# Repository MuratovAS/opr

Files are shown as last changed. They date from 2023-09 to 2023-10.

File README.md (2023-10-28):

# OPR
Open pocket router

## Screenshots

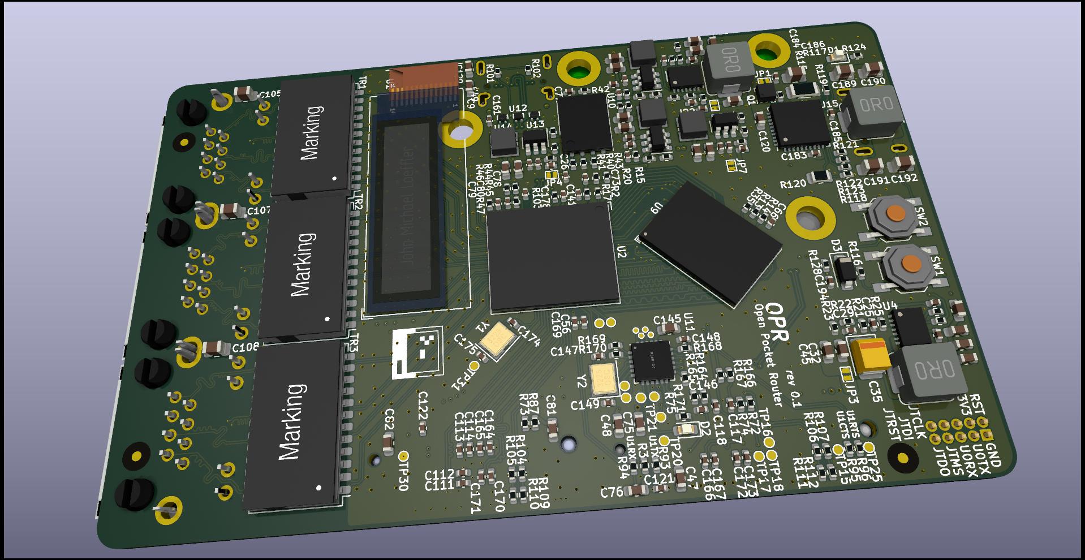
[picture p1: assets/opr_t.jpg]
Top view

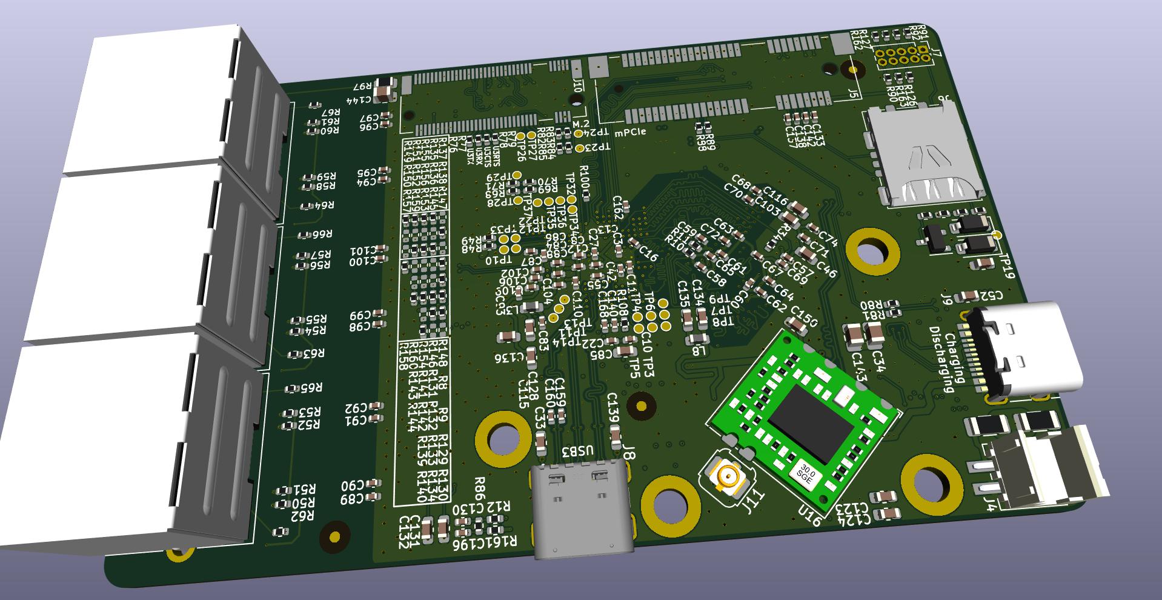
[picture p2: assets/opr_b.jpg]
Bottom view

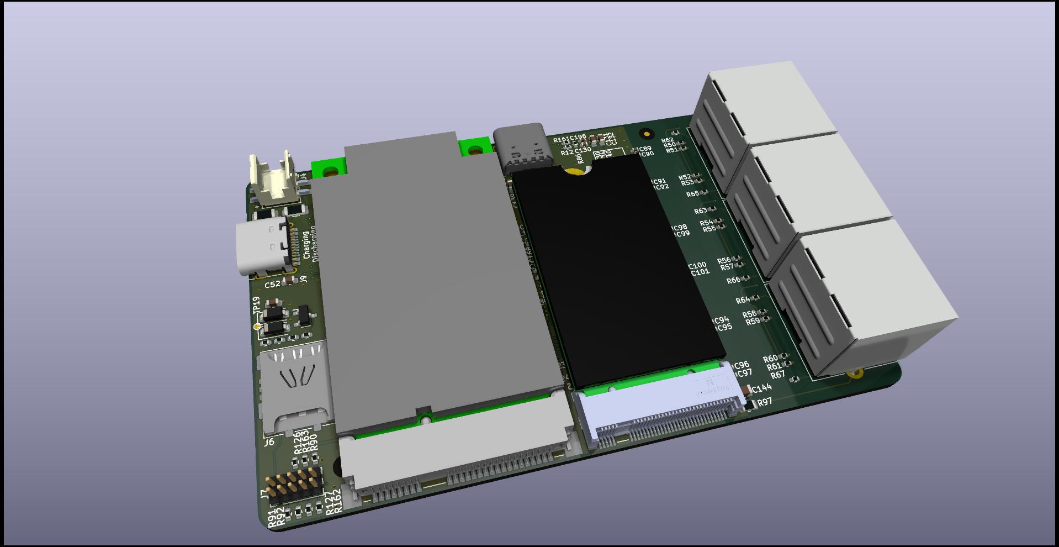
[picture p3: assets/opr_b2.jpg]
Bottom view 2


## In developing!!!

If you have questions, write suggestions in `Issues`

## Description
TODO:

## Specification

- CPU: MT7621A
- RAM: 2Gbit DDR3 
- USB: 3.0
- ETH: 3xGbE (RJ45)
- Display: SSD1306-0.91
- Flash: W25Q256FVEIG
- PowerBank: IP5328P
- Connectors: M.2 (2xPCIe+UART); mPCIe (1xPCIe+I2C+USB2+UART)
- PCB: 6 layers; JLC06161H-3313; Epoxy Filled & Capped; 0.15mm/0.3mm Via 

## Supported modules

- WIFI: MT7612E/MT7603E (x2 mPCIe)

## Changelog:

### v 0.1
- init

## Credit
```
https://github.com/kellertk/pwnagotchi-plugin-pisugar2
https://github.com/YC-Lammy/IP5328P-powerbank_design
https://github.com/zhaoxinyu0113/MT7621A_Router_HW_DIY'
https://github.com/cyijun/MT7621A-Router-Design
https://www.cnx-software.com/2015/05/14/firewrt-is-an-openwrt-802-11ac-board-powered-by-mediatek-mt7621a-processor/
https://bbs.t-firefly.com/forum.php?mod=viewthread&tid=543
http://en.techinfodepot.shoutwiki.com/wiki/Firefly_FireWRT
https://wikidevi.wi-cat.ru/MediaTek
https://whycan.com/t_2230.html
http://bbs.ntpcb.com/read-htm-tid-44619.html
https://www.elecfans.com/soft/21/2020/202003111179546.html
```

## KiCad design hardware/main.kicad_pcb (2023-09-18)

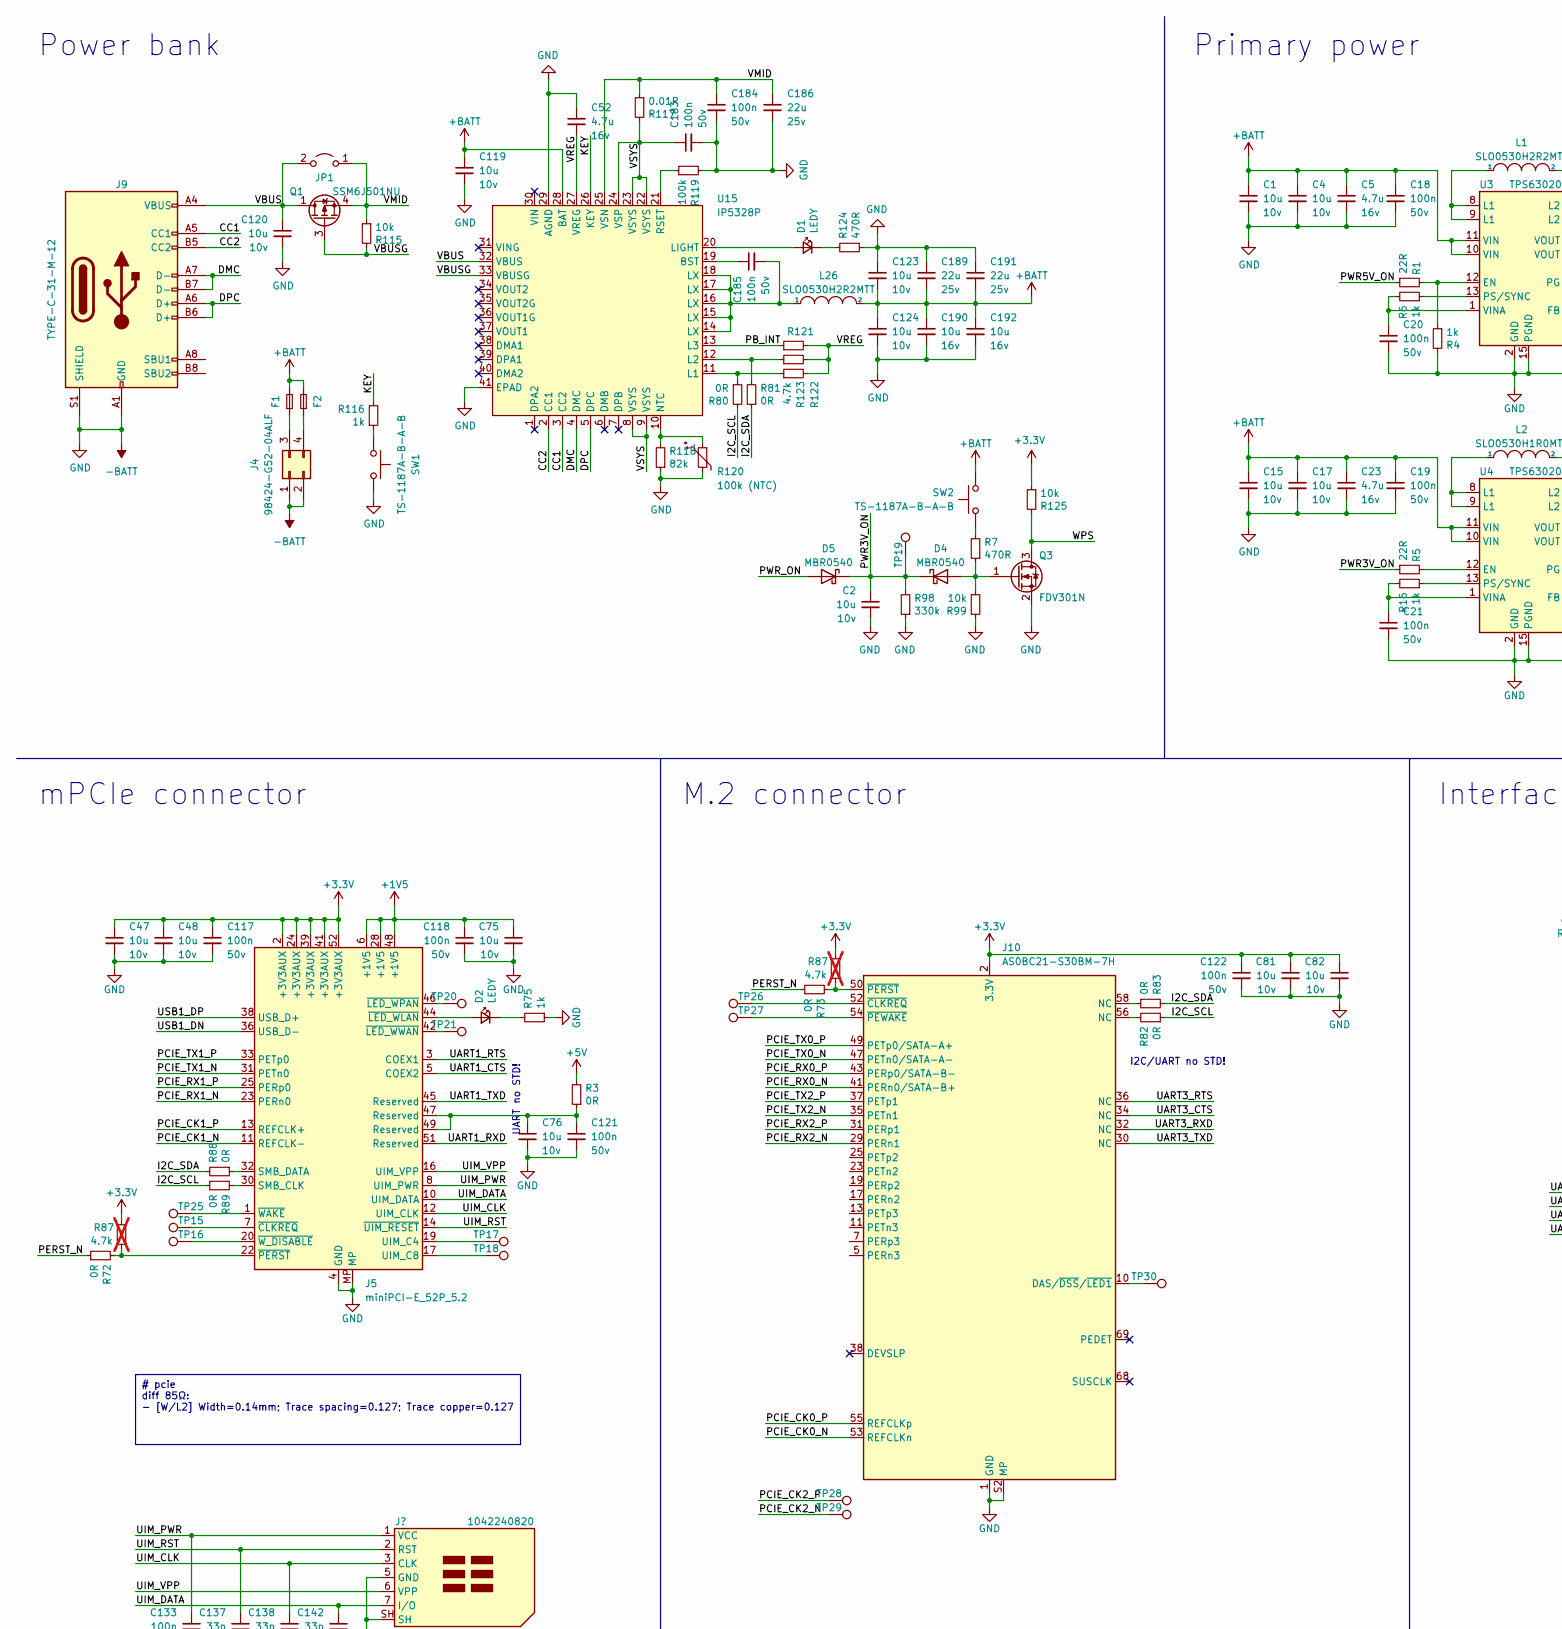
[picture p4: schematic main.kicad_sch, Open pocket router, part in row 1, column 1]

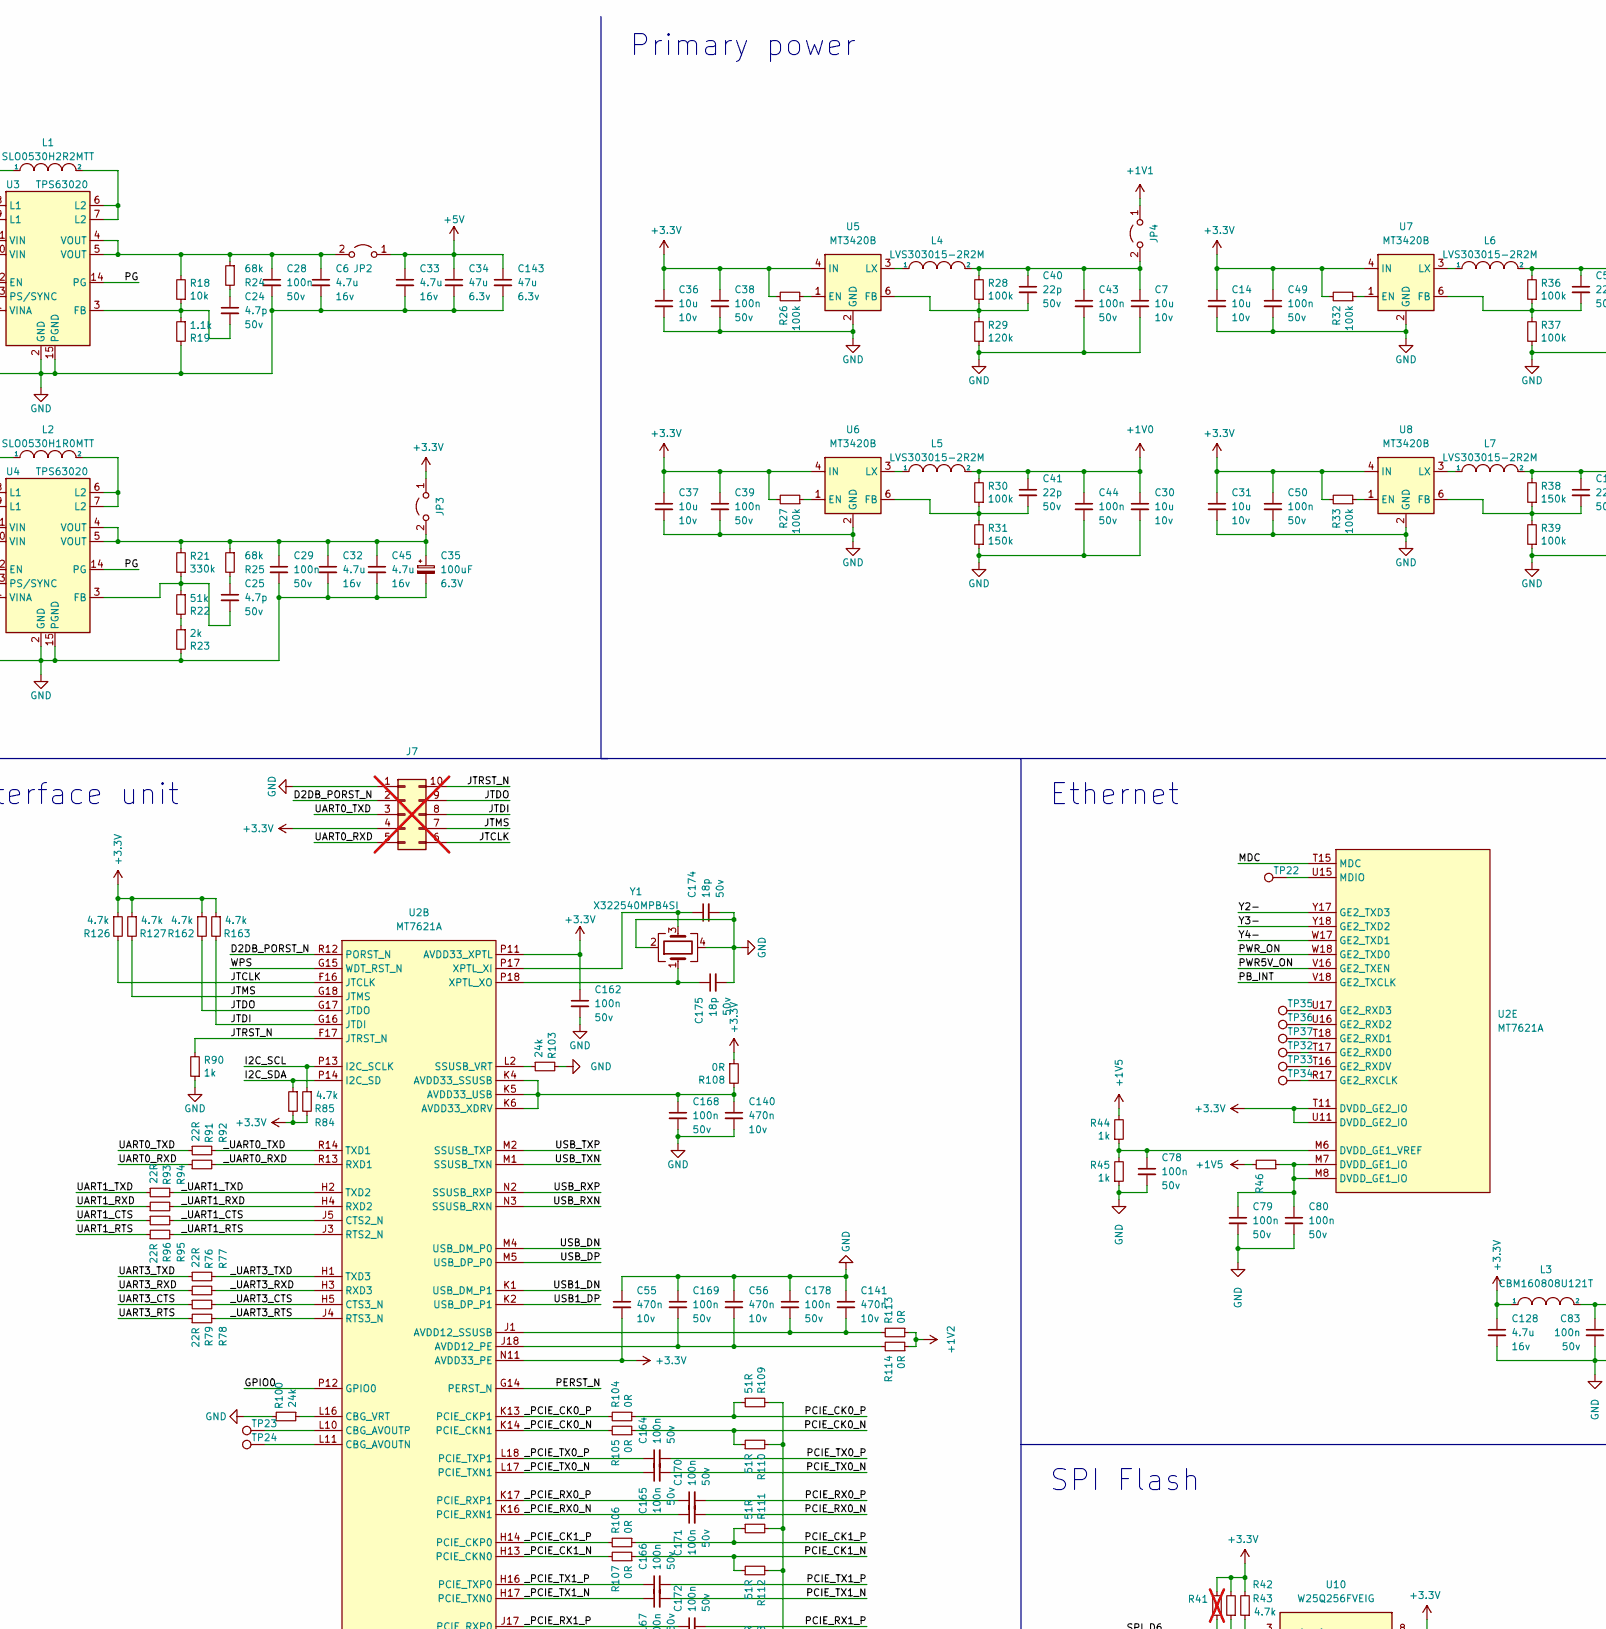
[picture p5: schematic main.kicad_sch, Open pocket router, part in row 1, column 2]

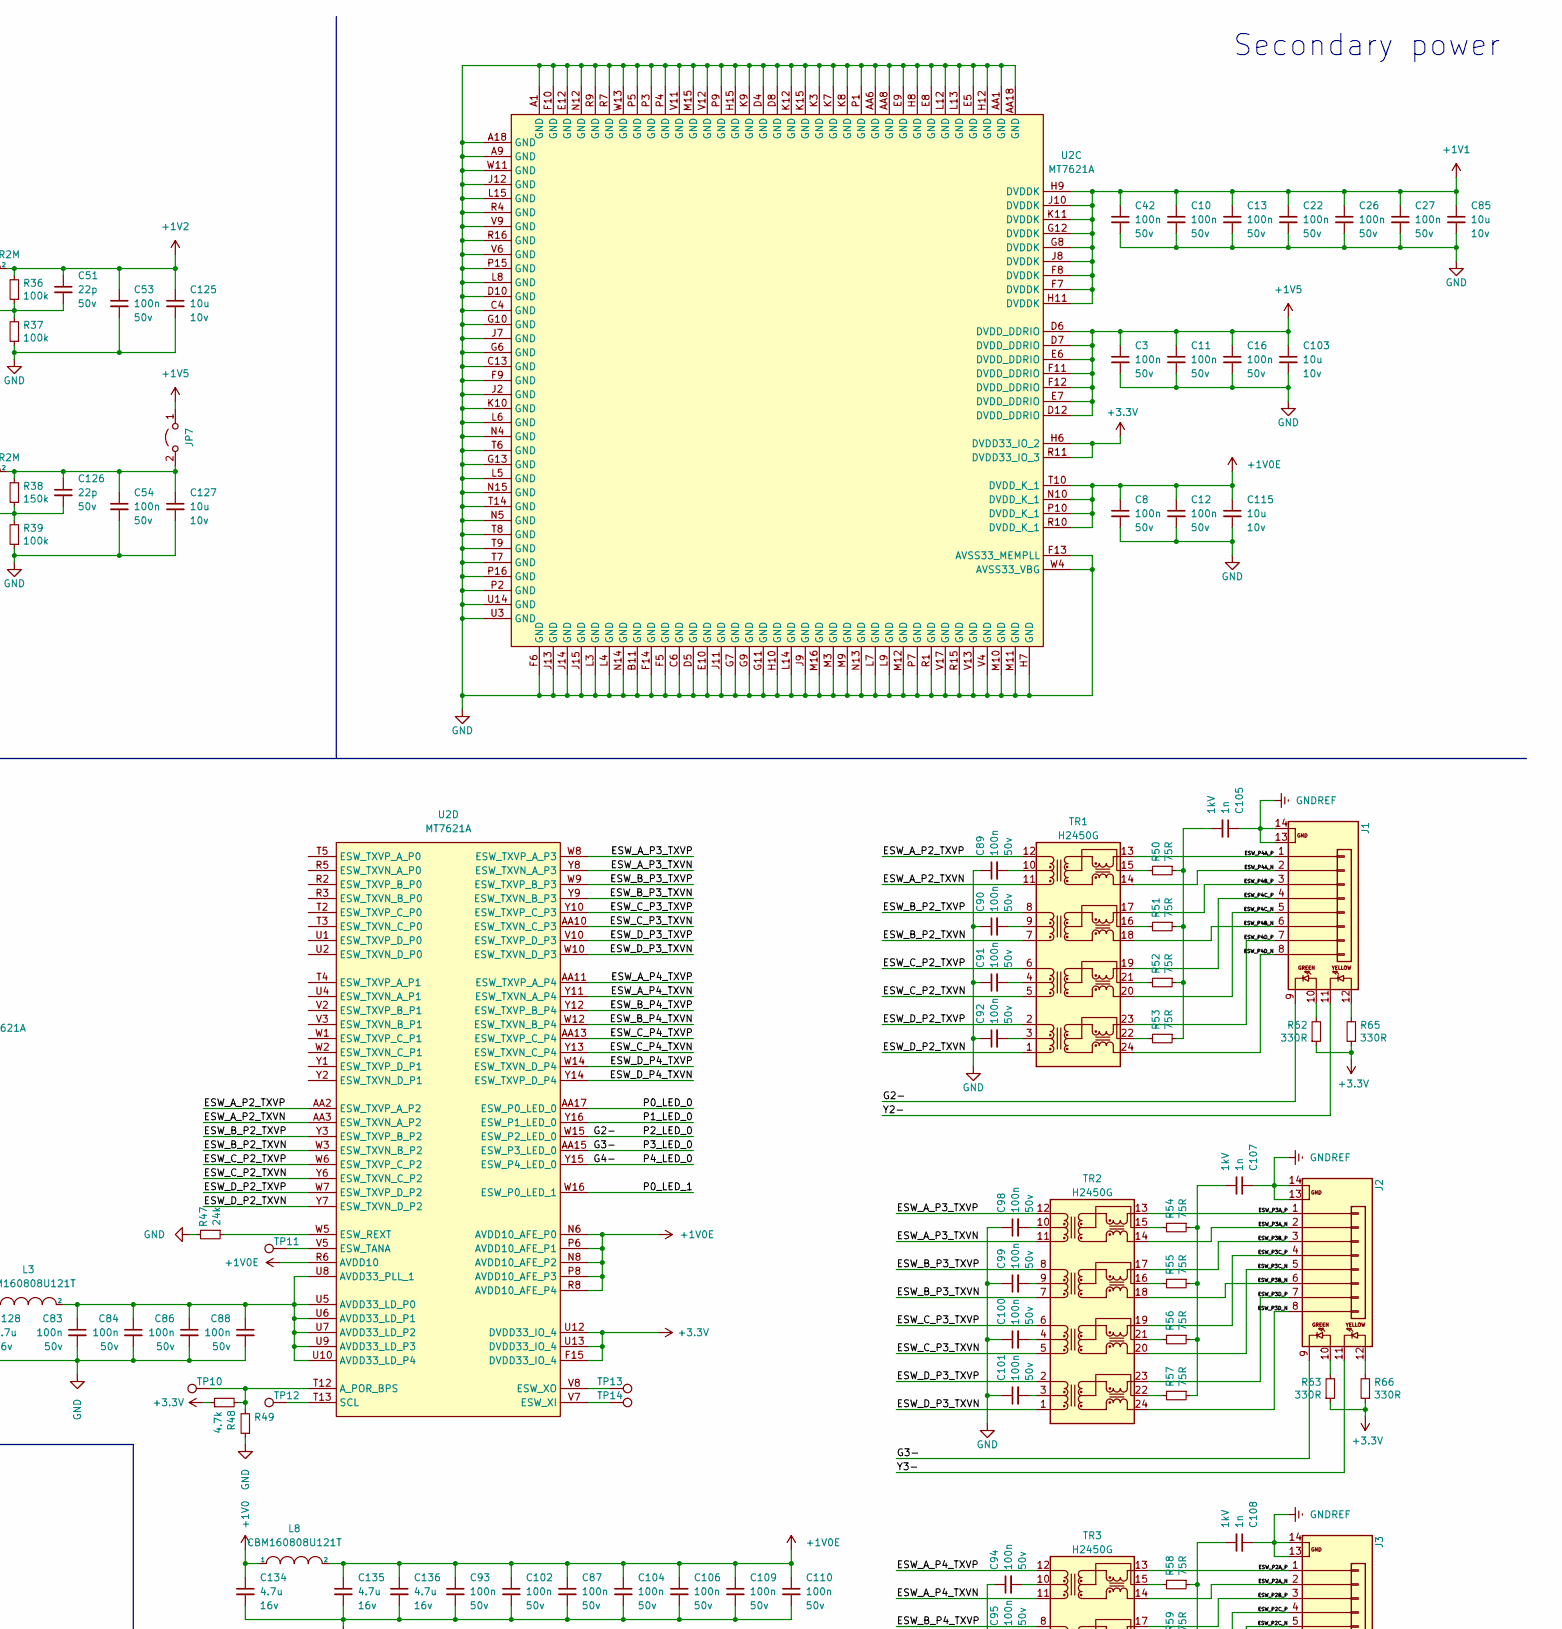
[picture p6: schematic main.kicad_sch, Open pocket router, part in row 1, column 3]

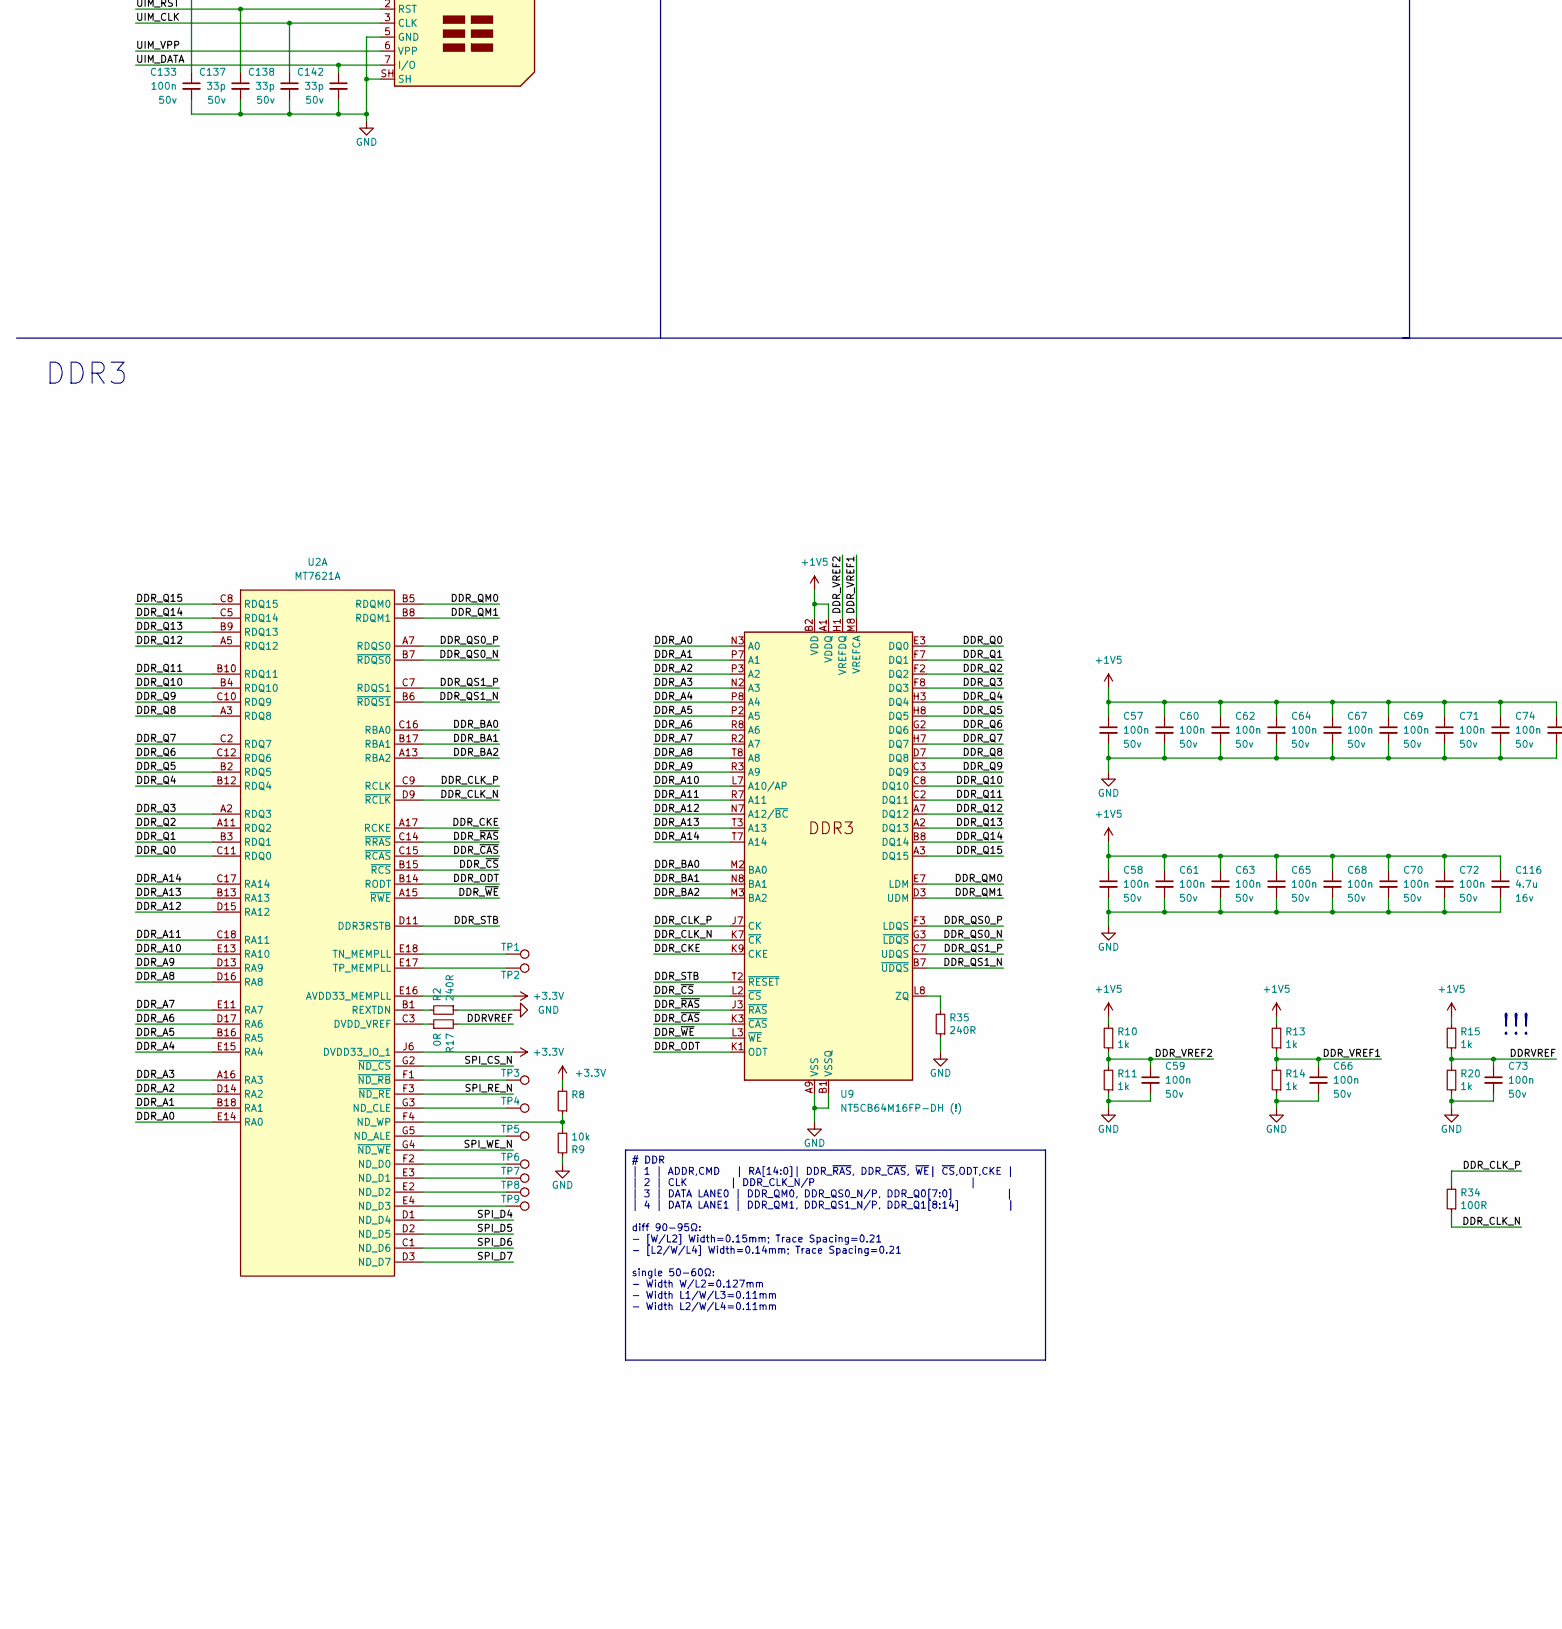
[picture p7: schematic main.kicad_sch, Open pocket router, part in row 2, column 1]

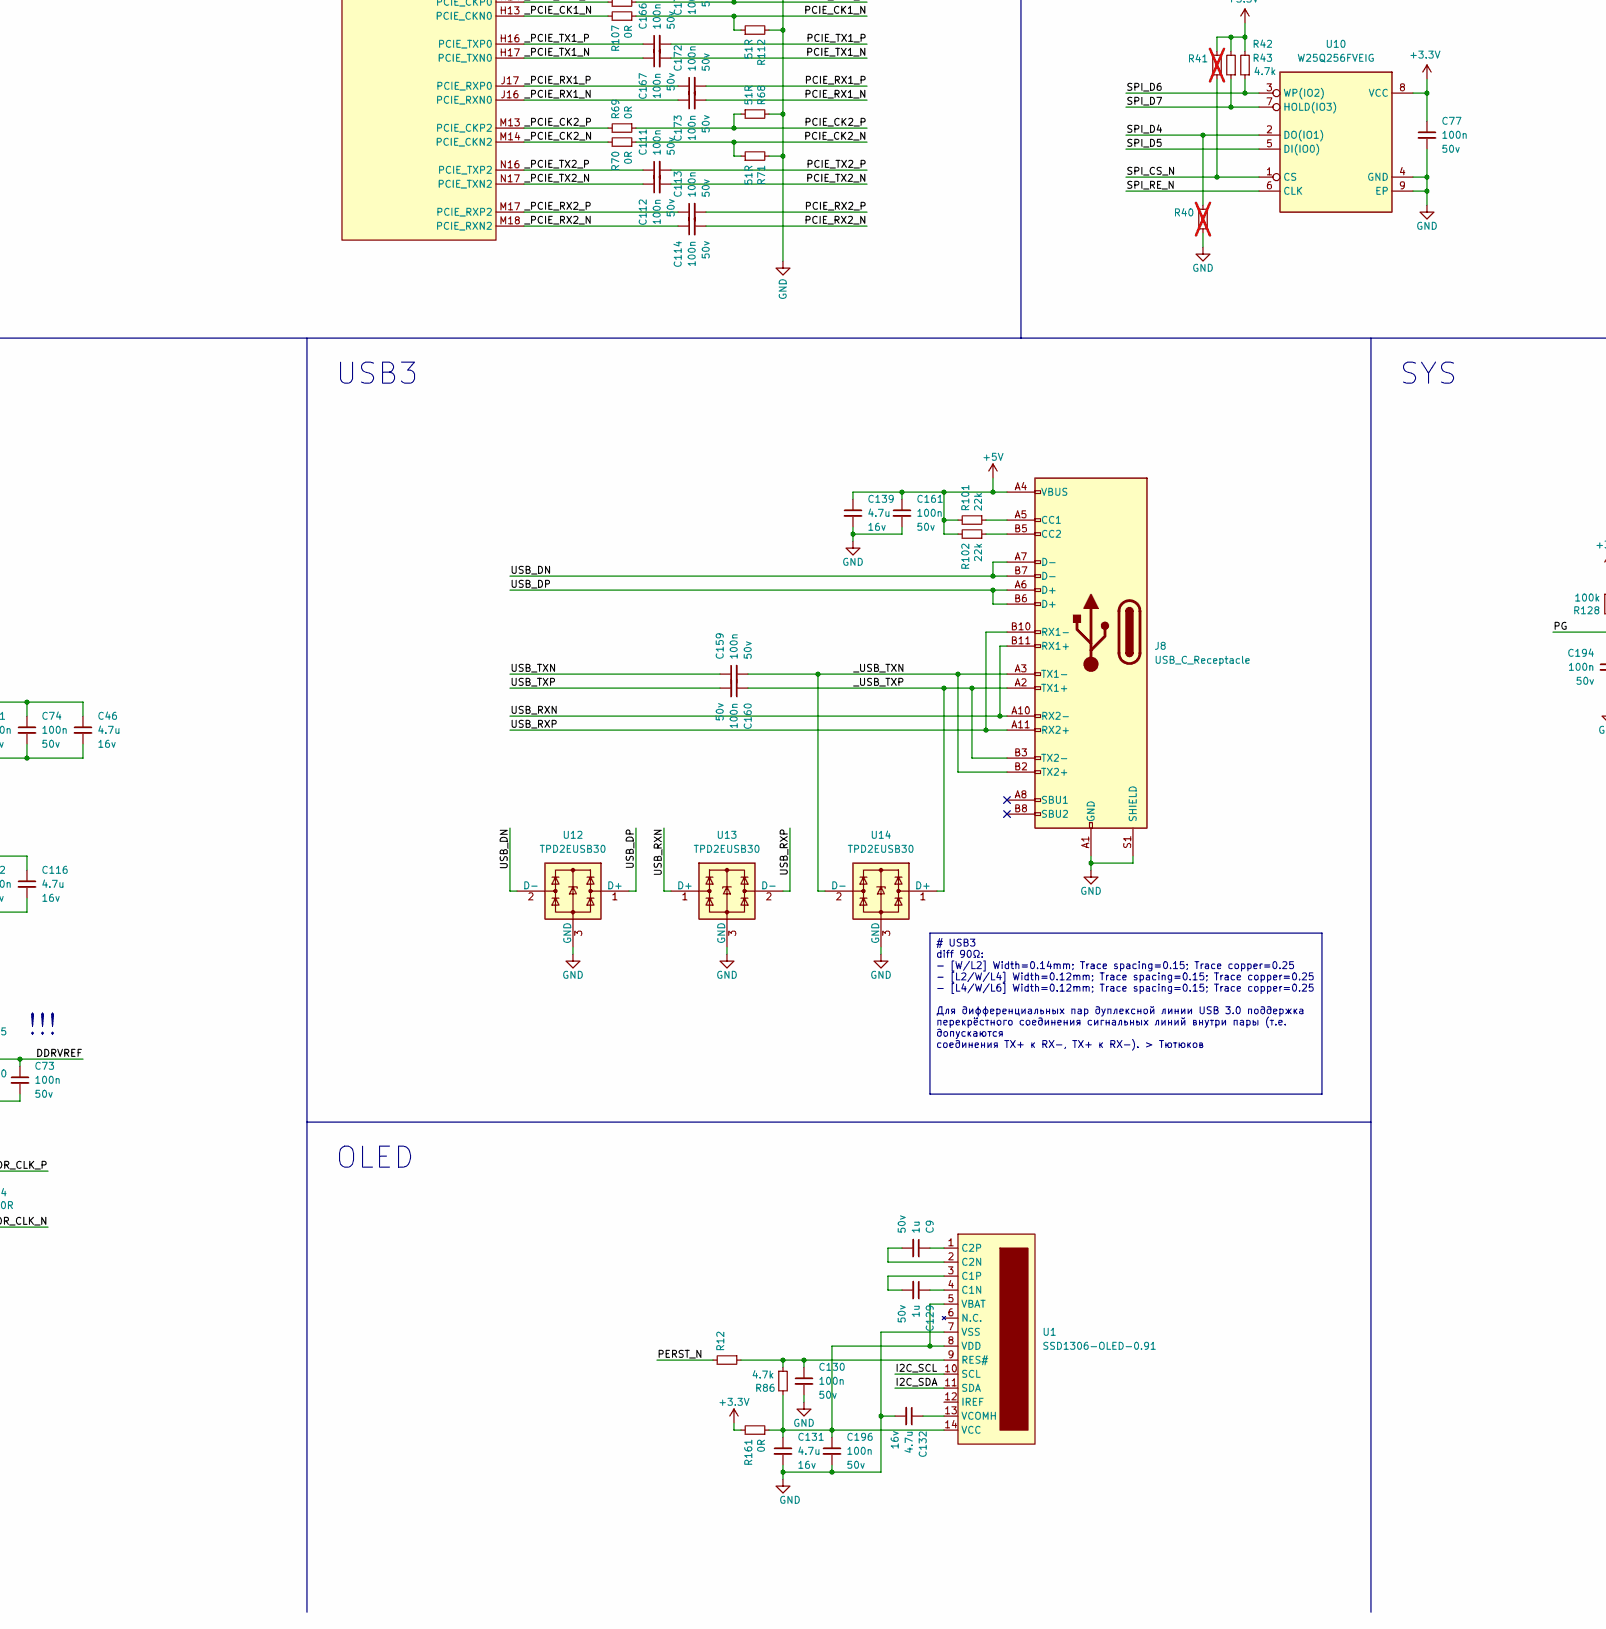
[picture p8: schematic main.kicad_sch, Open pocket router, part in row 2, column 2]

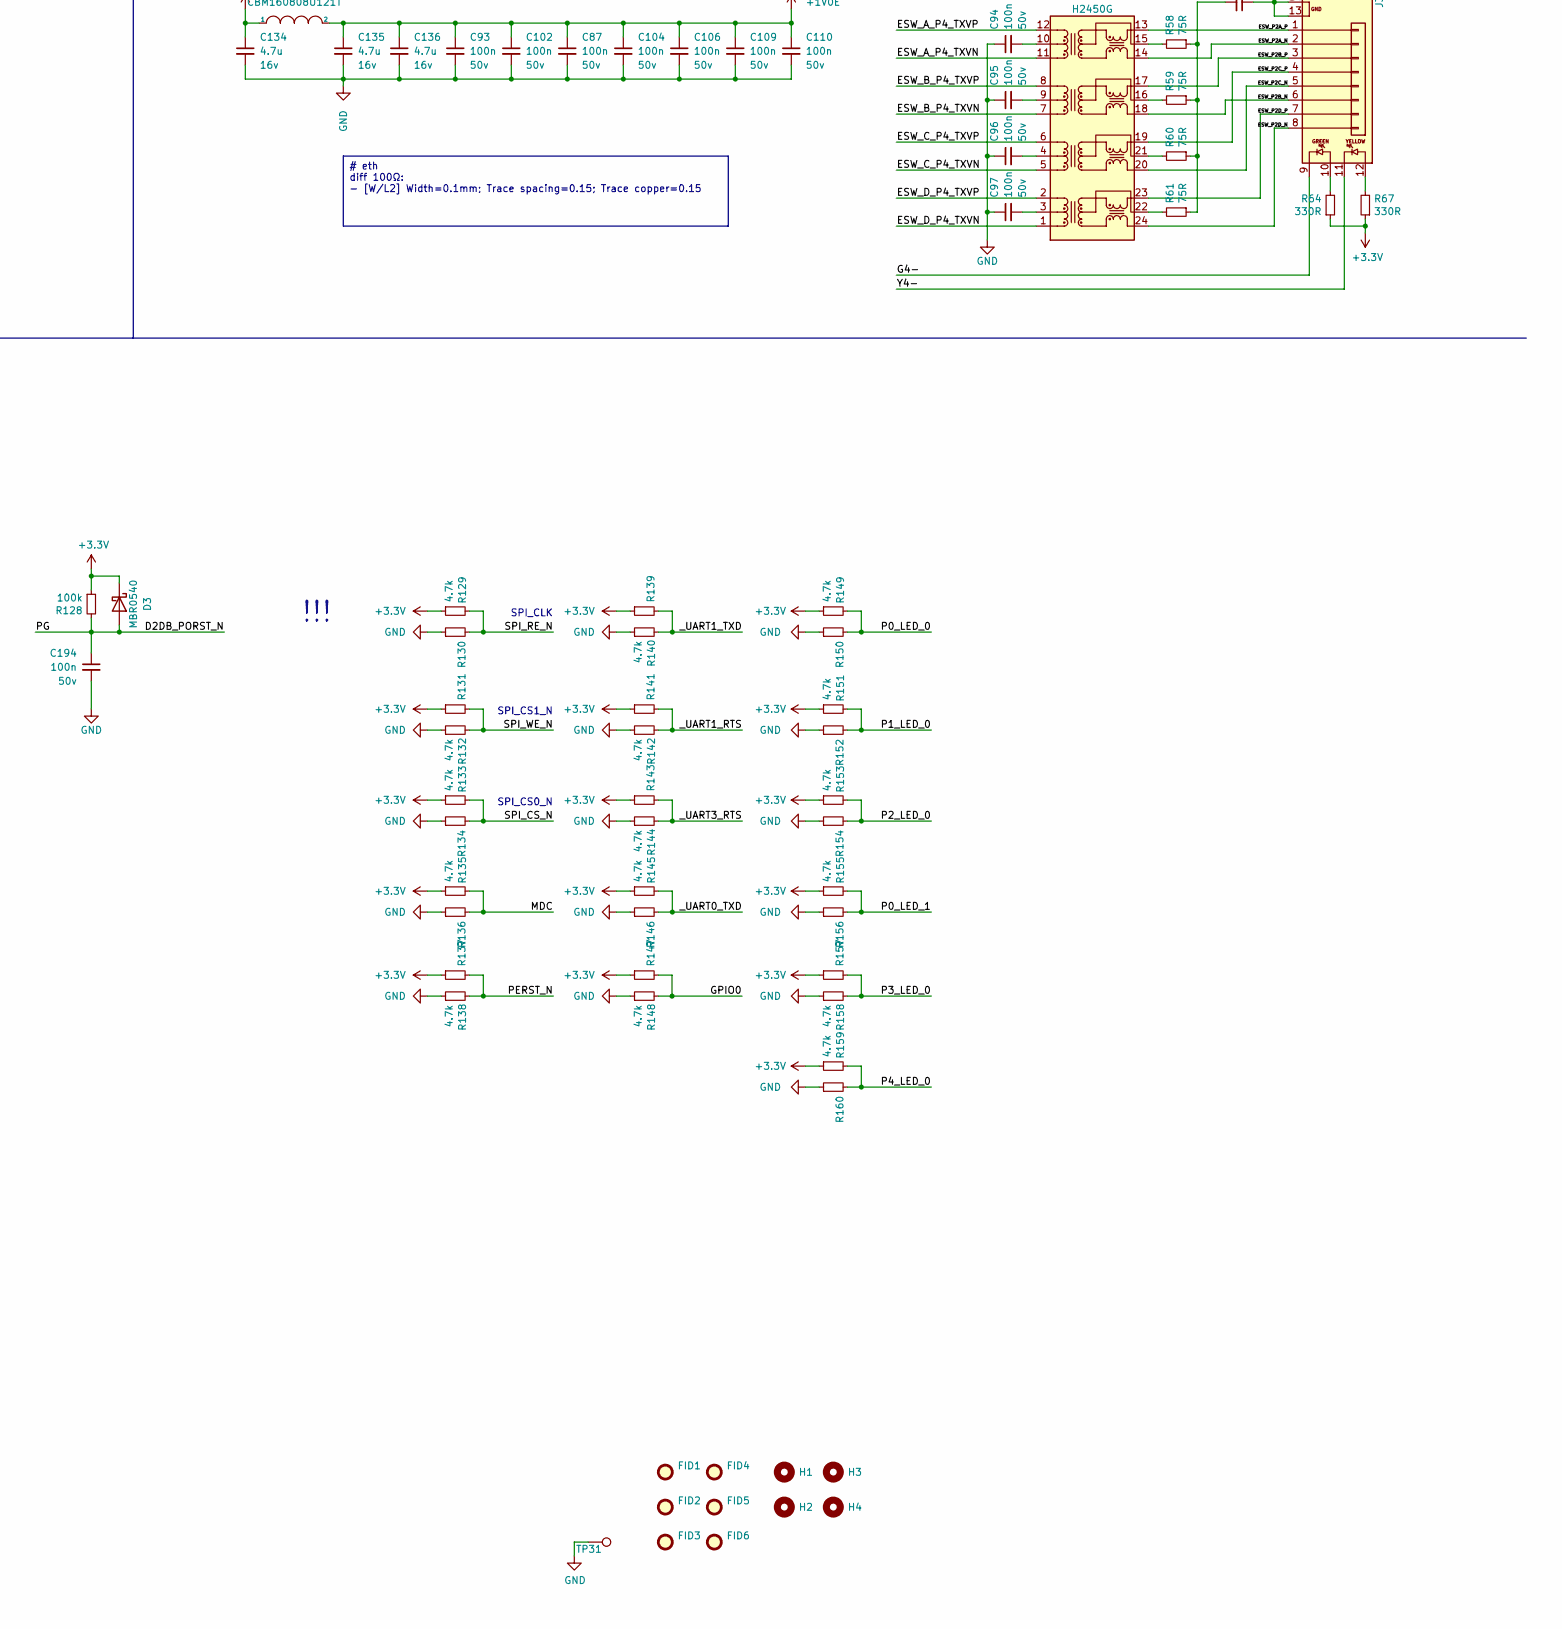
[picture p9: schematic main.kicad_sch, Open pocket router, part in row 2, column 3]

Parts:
C1, C2, C4, C7, C14, C15, C17, C30, C31, C36, C37, C47, C48, C75, C76, C81, C82, C85, C103, C115, C119, C120, C123, C124, C125, C127: 10u; C_0603_1608Metric; Voltage 10v; lcsc C19702
C3, C8, C10, C11, C12, C13, C16, C18, C19, C20, C21, C22, C26, C27, C28, C29, C38, C39, C42, C43, C44, C49, C50, C53, C54, C57, C58, C59, C60, C61, C62, C63, C64, C65, C66, C67, C68, C69, C70, C71, C72, C73, C74, C77, C78, C79, C80, C83, C84, C86, C87, C88, C89, C90, C91, C92, C93, C94, C95, C96, C97, C98, C99, C100, C101, C102, C104, C106, C109, C110, C111, C112, C113, C114, C117, C118, C121, C122, C130, C133, C159, C160, C161, C162, C164, C165, C166, C167, C168, C169, C170, C171, C172, C173, C178, C183, C184, C185, C194, C196: 100n; C_0402_1005Metric; Voltage 50v; lcsc C307331
C5, C6, C23, C32, C33, C45, C46, C52, C116, C128, C131, C132, C134, C135, C136, C139: 4.7u; C_0603_1608Metric; Voltage 16v; lcsc C19666
C9, C129: 1u; C_0603_1608Metric; Voltage 50v; lcsc C15849
C24, C25: 4.7p; C_0402_1005Metric; Voltage 50v; lcsc C1569
C34, C143: 47u; C_0805_2012Metric; Voltage 6.3v; lcsc C16780
C35: 100uF; CP_EIA-3528-21_Kemet-B; Voltage 6.3V; lcsc C16133
C40, C41, C51, C126: 22p; C_0402_1005Metric; Voltage 50v; lcsc C1555
C55, C56, C140, C141: 470n; C_0402_1005Metric; Voltage 10v; lcsc C47339
C105, C107, C108: 1n; C_0805_2012Metric; Voltage 1kV; lcsc C303890
C137, C138, C142: 33p; C_0402_1005Metric; Voltage 50v; lcsc C1562
C174, C175: 18p; C_0402_1005Metric; Voltage 50v; lcsc C1549
C186, C189, C191: 22u; C_0805_2012Metric; Voltage 25v; lcsc C45783
C190, C192: 10u; C_0805_2012Metric; Voltage 16v; lcsc C95841
D1, D2: LEDY; D_0603_1608Metric; lcsc C72038
D3, D4, D5: MBR0540; D_SOD-123
F1, F2: 12T.30000063AG12S1B02; Fuse_1206_3216Metric; lcsc C140478
FID1, FID2, FID3, FID4, FID5, FID6: F; Fiducial_1mm_Mask3mm
H1, H2, H3, H4: H; MountingHole_3.2mm_M3_DIN965_Pad
J1, J2, J3: DS1128-09-S8B8X; RJ45_DS1128-09-S8B8X; lcsc C86578
J4: 98424-G52-04ALF; PinSocket_2x02_P2.00mm_Vertical_SMD; lcsc C216040
J5: miniPCI-E_52P_5.2; BUS_PCI_Express_Mini_Dual; lcsc C16250
J7: PinHeader_2x05_P1.27mm_Vertical; not fitted
J8: USB_C_Receptacle; HRS_CX90B1-24P; lcsc C2681555
J9: TYPE-C-31-M-12; USB_C_Receptacle_HRO_TYPE-C-31-M-12; lcsc C165948
J10: AS0BC21-S30BM-7H; Bus_M.2_Socket_M; lcsc C2832351
JP1, JP2, JP3, JP4, JP7: JP; SolderJumper_Open_Pad0.5x0.8mm
L1, L26: SLO0530H2R2MTT; Power_inductor_SMD_0530; lcsc C325962
L2: SLO0530H1R0MTT; Power_inductor_SMD_0530; lcsc C325960
L3, L8: CBM160808U121T; L_0603_1608Metric; lcsc C62708
L4, L5, L6, L7: LVS303015-2R2M; L_Wuerth_MAPI-3015; lcsc C285837
Q1: SSM6J501NU; U-MOSVI; lcsc C146326
Q3: FDV301N; SOT-23; lcsc C15310
R1, R5, R76, R77, R78, R79, R91, R92, R93, R94, R95, R96: 22R; R_0402_1005Metric; lcsc C25092
R2, R35: 240R; R_0402_1005Metric; lcsc C114755
R3, R17, R69, R70, R72, R73, R80, R81, R82, R83, R88, R89, R104, R105, R106, R107, R108, R113, R114, R161: 0R; R_0402_1005Metric; lcsc C17168
R4, R6, R10, R11, R13, R14, R15, R16, R20, R44, R45, R75, R90, R116: 1k; R_0402_1005Metric; lcsc C11702
R7, R124: 470R; R_0402_1005Metric; lcsc C25117
R8, R12, R46, R49, R121, R130, R131, R134, R136, R137, R139, R141, R143, R146, R147, R150, R152, R154, R156, R157, R160: R_0402_1005Metric
R9, R18, R99, R115, R125: 10k; R_0402_1005Metric; lcsc C25744
R19: 1.1k; R_0402_1005Metric; lcsc C325543
R21, R98: 330k; R_0402_1005Metric; lcsc C25778
R22: 51k; R_0402_1005Metric; lcsc C25794
R23: 2k; R_0402_1005Metric; lcsc C100608
R24, R25: 68k; R_0402_1005Metric; lcsc C36871
R26, R27, R28, R30, R32, R33, R36, R37, R39, R119, R128: 100k; R_0402_1005Metric; lcsc C25741
R29: 120k; R_0402_1005Metric; lcsc C25750
R31, R38: 150k; R_0402_1005Metric; lcsc C25755
R34: 100R; R_0402_1005Metric; lcsc C153111
R40, R41: R_0402_1005Metric; not fitted
R42, R43, R48, R84, R85, R86, R122, R123, R126, R127, R129, R132, R133, R135, R138, R140, R142, R144, R145, R148, R149, R151, R153, R155, R158, R159, R162, R163: 4.7k; R_0402_1005Metric; lcsc C25900
R47, R100, R103: 24k; R_0402_1005Metric; lcsc C25769
R50, R51, R52, R53, R54, R55, R56, R57, R58, R59, R60, R61: 75R; R_0402_1005Metric; lcsc C25133
R62, R63, R64, R65, R66, R67: 330R; R_0402_1005Metric; lcsc C25104
R68, R71, R109, R110, R111, R112: 51R; R_0402_1005Metric; lcsc C25125
R87: 4.7k; R_0402_1005Metric; lcsc C25900; not fitted
R101, R102: 22k; R_0402_1005Metric; lcsc C25768
R117: 0.01R; R_1206_3216Metric; lcsc C778444
R118: 82k; R_0402_1005Metric; lcsc C137932
R120: 100k (NTC); R_0805_2012Metric; lcsc C95970
SW1, SW2: TS-1187A-B-A-B; SW_SPST_TL3342; lcsc C318884
TP1, TP2, TP3, TP4, TP5, TP6, TP7, TP8, TP9, TP10, TP11, TP12, TP13, TP14, TP15, TP16, TP17, TP18, TP19, TP20, TP21, TP22, TP23, TP24, TP25, TP26, TP27, TP28, TP29, TP30, TP31, TP32, TP33, TP34, TP35, TP36, TP37: TP; TestPoint_Pad_D1mm
TR1, TR2, TR3: H2450G; Transformer_Ethernet_E-NETTR_24; lcsc C4155005
U1: SSD1306-OLED-0.91; SSD1306-oled-0.91
U2: MT7621A; TFBGA-387_11.7x13.6mm_P0.65mm
U3, U4: TPS63020; DFN-14-1EP_3x4mm_P0.5mm_EP1.7x3.3mm; lcsc C15483
U5, U6, U7, U8: MT3420B; SOT-23-6; lcsc C88169
U9: NT5CB64M16FP-DH (!); BGA-96_9.0x13.0mm_Layout2x3x16_P0.8mm; lcsc C2909894
U10: W25Q256FVEIG; WSON-8-1EP_8x6mm_P1.27mm_EP3.4x4mm; lcsc C2803442
U12, U13, U14: TPD2EUSB30; Texas_DRT-3; lcsc C2844720
U15: IP5328P; QFN-40-1EP_6x6mm_P0.5mm_EP4.6x4.6mm
Y1: X322540MPB4SI; Oscillator_SMD_SMD3225-4P; lcsc C9010

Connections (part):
+1V0: C30.1, C41.1, C44.1, C134.1, L5.2, L8.1, R30.2
+1V0E: C8.1, C12.1, C87.1, C93.1, C102.1, C104.1, C106.1, C109.1, C110.1, C115.1, C135.1, C136.1, L8.2, U2.N6 (AVDD10_AFE_P0), U2.N8 (AVDD10_AFE_P2), U2.N10 (DVDD_K_1), U2.P6 (AVDD10_AFE_P1), U2.P8 (AVDD10_AFE_P3), U2.P10 (DVDD_K_1), U2.R6 (AVDD10), U2.R8 (AVDD10_AFE_P4), U2.R10 (DVDD_K_1), U2.T10 (DVDD_K_1)
+1V1: C10.1, C13.1, C22.1, C26.1, C27.1, C42.1, C85.1, JP4.1 (A), U2.F7 (DVDDK), U2.F8 (DVDDK), U2.G8 (DVDDK), U2.G12 (DVDDK), U2.H9 (DVDDK), U2.H11 (DVDDK), U2.J8 (DVDDK), U2.J10 (DVDDK), U2.K11 (DVDDK)
+1V2: C51.1, C53.1, C125.1, L6.2, R36.2, R113.1, R114.1
+1V5: C3.1, C11.1, C16.1, C46.1, C57.1, C58.1, C60.1, C61.1, C62.1, C63.1, C64.1, C65.1, C67.1, C68.1, C69.1, C70.1, C71.1, C72.1, C74.1, C75.1, C103.1, C116.1, C118.1, J5.6 (+1V5), J5.28 (+1V5), J5.48 (+1V5), JP7.1 (A), R10.2, R13.2, R15.2, R44.2, R46.2, U2.D6 (DVDD_DDRIO), U2.D7 (DVDD_DDRIO), U2.D12 (DVDD_DDRIO), U2.E6 (DVDD_DDRIO), U2.E7 (DVDD_DDRIO), U2.F11 (DVDD_DDRIO), U2.F12 (DVDD_DDRIO), U9.A1 (VDDQ), U9.A8 (VDDQ), U9.B2 (VDD), U9.C1 (VDDQ), U9.C9 (VDDQ), U9.D2 (VDDQ), U9.D9 (VDD), U9.E9 (VDDQ), U9.F1 (VDDQ), U9.G7 (VDD), U9.H2 (VDDQ), U9.H9 (VDDQ), U9.K2 (VDD), U9.K8 (VDD), U9.N1 (VDD), U9.N9 (VDD), U9.R1 (VDD), U9.R9 (VDD)
+3V3: C14.1, C31.1, C36.1, C37.1, C38.1, C39.1, C47.1, C48.1, C49.1, C50.1, C55.2, C77.1, C81.1, C82.1, C117.1, C122.1, C128.1, C162.1, D3.1 (K), J5.2 (+3V3AUX), J5.24 (+3V3AUX), J5.39 (+3V3AUX), J5.41 (+3V3AUX), J5.52 (+3V3AUX), J7.4, J10.2 (3.3V), J10.4 (3.3V), J10.12 (3.3V), J10.14 (3.3V), J10.16 (3.3V), J10.18 (3.3V), J10.70 (3.3V), J10.72 (3.3V), J10.74 (3.3V), JP3.1 (A), L3.1, R8.2, R26.2, R27.2, R32.2, R33.2, R41.2, R42.2, R43.2, R48.1, R62.1, R63.1, R64.1, R65.1, R66.1, R67.1, R84.2, R85.2, R87.2, R108.1, R125.1, R126.1, R127.1, R128.1, R129.1, R131.1, R133.1, R135.1, R137.1, R139.1, R141.1, R143.1, R145.1, R147.1, R149.1, R151.1, R153.1, R155.1, R157.1, R159.1, R161.2, R162.1, R163.1, U2.E16 (AVDD33_MEMPLL), U2.F15 (DVDD33_IO_4)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; also elsewhere on the board
+5V: C33.1, C34.1, C139.1, C143.1, C161.1, J8.A4 (VBUS), J8.A9 (VBUS), J8.B4 (VBUS), J8.B9 (VBUS), JP2.1 (A), R3.2, R101.2, R102.2
+BATT: C1.1, C4.1, C5.1, C15.1, C17.1, C18.1, C19.1, C23.1, C119.1, C123.2, C124.1, C189.2, C190.1, C191.2, C192.1, F1.2, F2.2, L26.2, SW2.2, U3.10 (VIN), U3.11 (VIN), U4.10 (VIN), U4.11 (VIN), U15.28 (BAT)
/CC1: J9.A5 (CC1), U15.3 (CC2)
/CC2: J9.B5 (CC2), U15.2 (CC1)
/D2DB_PORST_N: C194.1, D3.2 (A), J7.2, R128.2, U2.R12 (PORST_N), U3.14 (PG), U4.14 (PG)
/DDRVREF: C73.1, R15.1, R17.2, R20.2
/DDR_A0: U2.E14 (RA0), U9.N3 (A0)
/DDR_A1: U2.B18 (RA1), U9.P7 (A1)
/DDR_A2: U2.D14 (RA2), U9.P3 (A2)
/DDR_A3: U2.A16 (RA3), U9.N2 (A3)
/DDR_A4: U2.E15 (RA4), U9.P8 (A4)
/DDR_A5: U2.B16 (RA5), U9.P2 (A5)
/DDR_A6: U2.D17 (RA6), U9.R8 (A6)
/DDR_A7: U2.E11 (RA7), U9.R2 (A7)
/DDR_A8: U2.D16 (RA8), U9.T8 (A8)
/DDR_A9: U2.D13 (RA9), U9.R3 (A9)
/DDR_A10: U2.E13 (RA10), U9.L7 (A10/AP)
/DDR_A11: U2.C18 (RA11), U9.R7 (A11)
/DDR_A12: U2.D15 (RA12), U9.N7 (A12/~BC)
/DDR_A13: U2.B13 (RA13), U9.T3 (A13)
/DDR_A14: U2.C17 (RA14), U9.T7 (A14)
/DDR_BA0: U2.C16 (RBA0), U9.M2 (BA0)
/DDR_BA1: U2.B17 (RBA1), U9.N8 (BA1)
/DDR_BA2: U2.A13 (RBA2), U9.M3 (BA2)
/DDR_CKE: U2.A17 (RCKE), U9.K9 (CKE)
/DDR_CLK_N: R34.1, U2.D9 (~RCLK), U9.K7 (~CK)
/DDR_CLK_P: R34.2, U2.C9 (RCLK), U9.J7 (CK)
/DDR_ODT: U2.B14 (RODT), U9.K1 (ODT)
/DDR_Q0: U2.C11 (RDQ0), U9.E3 (DQ0)
/DDR_Q1: U2.B3 (RDQ1), U9.F7 (DQ1)
/DDR_Q2: U2.A11 (RDQ2), U9.F2 (DQ2)
/DDR_Q3: U2.A2 (RDQ3), U9.F8 (DQ3)
/DDR_Q4: U2.B12 (RDQ4), U9.H3 (DQ4)
/DDR_Q5: U2.B2 (RDQ5), U9.H8 (DQ5)
/DDR_Q6: U2.C12 (RDQ6), U9.G2 (DQ6)
/DDR_Q7: U2.C2 (RDQ7), U9.H7 (DQ7)
/DDR_Q8: U2.A3 (RDQ8), U9.D7 (DQ8)
/DDR_Q9: U2.C10 (RDQ9), U9.C3 (DQ9)
/DDR_Q10: U2.B4 (RDQ10), U9.C8 (DQ10)
/DDR_Q11: U2.B10 (RDQ11), U9.C2 (DQ11)
/DDR_Q12: U2.A5 (RDQ12), U9.A7 (DQ12)
/DDR_Q13: U2.B9 (RDQ13), U9.A2 (DQ13)
/DDR_Q14: U2.C5 (RDQ14), U9.B8 (DQ14)
/DDR_Q15: U2.C8 (RDQ15), U9.A3 (DQ15)
/DDR_QM0: U2.B5 (RDQM0), U9.E7 (LDM)
/DDR_QM1: U2.B8 (RDQM1), U9.D3 (UDM)
/DDR_QS0_N: U2.B7 (~RDQS0), U9.G3 (~LDQS)
/DDR_QS0_P: U2.A7 (RDQS0), U9.F3 (LDQS)
/DDR_QS1_N: U2.B6 (~RDQS1), U9.B7 (~UDQS)
/DDR_QS1_P: U2.C7 (RDQS1), U9.C7 (UDQS)
/DDR_STB: U2.D11 (DDR3RSTB), U9.T2 (~RESET)
/DDR_VREF1: C66.1, R13.1, R14.2, U9.M8 (VREFCA)
/DDR_VREF2: C59.1, R10.1, R11.2, U9.H1 (VREFDQ)
/DDR_~CAS: U2.C15 (~RCAS), U9.K3 (~CAS)
/DDR_~CS: U2.B15 (~RCS), U9.L2 (~CS)
/DDR_~RAS: U2.C14 (~RRAS), U9.J3 (~RAS)
/DDR_~WE: U2.A15 (~RWE), U9.L3 (~WE)
/DMC: J9.A7 (D-), J9.B7 (D-), U15.4 (DMC)
/DPC: J9.A6 (D+), J9.B6 (D+), U15.5 (DPC)
/ESW_A_P2_TXVN: TR1.11 (TD4+), U2.AA3 (ESW_TXVN_A_P2)
/ESW_A_P2_TXVP: TR1.12 (TD4-), U2.AA2 (ESW_TXVP_A_P2)
/ESW_A_P3_TXVN: TR2.11 (TD4+), U2.Y8 (ESW_TXVN_A_P3)
/ESW_A_P3_TXVP: TR2.12 (TD4-), U2.W8 (ESW_TXVP_A_P3)
/ESW_A_P4_TXVN: TR3.11 (TD4+), U2.Y11 (ESW_TXVN_A_P4)
/ESW_A_P4_TXVP: TR3.12 (TD4-), U2.AA11 (ESW_TXVP_A_P4)
/ESW_B_P2_TXVN: TR1.7 (CT), U2.W3 (ESW_TXVN_B_P2)
/ESW_B_P2_TXVP: TR1.8 (TD3+), U2.Y3 (ESW_TXVP_B_P2)
/ESW_B_P3_TXVN: TR2.7 (CT), U2.Y9 (ESW_TXVN_B_P3)
/ESW_B_P3_TXVP: TR2.8 (TD3+), U2.W9 (ESW_TXVP_B_P3)
/ESW_B_P4_TXVN: TR3.7 (CT), U2.W12 (ESW_TXVN_B_P4)
/ESW_B_P4_TXVP: TR3.8 (TD3+), U2.Y12 (ESW_TXVP_B_P4)
/ESW_C_P2_TXVN: TR1.5 (TD2+), U2.Y6 (ESW_TXVN_C_P2)
/ESW_C_P2_TXVP: TR1.6 (TD2-), U2.W6 (ESW_TXVP_C_P2)
/ESW_C_P3_TXVN: TR2.5 (TD2+), U2.AA10 (ESW_TXVN_C_P3)
/ESW_C_P3_TXVP: TR2.6 (TD2-), U2.Y10 (ESW_TXVP_C_P3)
/ESW_C_P4_TXVN: TR3.5 (TD2+), U2.Y13 (ESW_TXVN_C_P4)
/ESW_C_P4_TXVP: TR3.6 (TD2-), U2.AA13 (ESW_TXVP_C_P4)
/ESW_D_P2_TXVN: TR1.1 (CT), U2.Y7 (ESW_TXVN_D_P2)
/ESW_D_P2_TXVP: TR1.2 (TD1+), U2.W7 (ESW_TXVP_D_P2)
/ESW_D_P3_TXVN: TR2.1 (CT), U2.W10 (ESW_TXVN_D_P3)
/ESW_D_P3_TXVP: TR2.2 (TD1+), U2.V10 (ESW_TXVP_D_P3)
/ESW_D_P4_TXVN: TR3.1 (CT), U2.Y14 (ESW_TXVP_D_P4)
/ESW_D_P4_TXVP: TR3.2 (TD1+), U2.W14 (ESW_TXVN_D_P4)
/ESW_P2C_P: J3.4, TR3.19 (MX2-)
/ESW_P2D_N: J3.8, TR3.24 (CT)
/ESW_P3A_N: J2.2, TR2.14 (MX4+)
/ESW_P3A_P: J2.1, TR2.13 (MX4-)
/ESW_P3B_N: J2.6, TR2.18 (CT)
/ESW_P3B_P: J2.3, TR2.17 (MX3+)
/ESW_P3C_N: J2.5, TR2.20 (MX2+)
/ESW_P3C_P: J2.4, TR2.19 (MX2-)
/ESW_P3D_N: J2.8, TR2.24 (CT)
/ESW_P3D_P: J2.7, TR2.23 (MX1+)
/ESW_P4A_N: J1.2, TR1.14 (MX4+)
/ESW_P4A_P: J1.1, TR1.13 (MX4-)
/ESW_P4B_N: J1.6, TR1.18 (CT)
/ESW_P4B_P: J1.3, TR1.17 (MX3+)
/ESW_P4C_N: J1.5, TR1.20 (MX2+)
/ESW_P4C_P: J1.4, TR1.19 (MX2-)
/ESW_P4D_N: J1.8, TR1.24 (CT)
/ESW_P4D_P: J1.7, TR1.23 (MX1+)
/G2-: J1.9, R153.2, R154.2, U2.W15 (ESW_P2_LED_0)
/G3-: J2.9, R157.2, R158.2, U2.AA15 (ESW_P3_LED_0)
/G4-: J3.9, R159.2, R160.2, U2.Y15 (ESW_P4_LED_0)
/GPIO0: R147.2, R148.2, U2.P12 (GPIO0)
/I2C_SCL: R80.2, R82.1, R85.1, R89.1, U1.10 (SCL), U2.P13 (I2C_SCLK)
/I2C_SDA: R81.1, R83.2, R84.1, R88.2, U1.11 (SDA), U2.P14 (I2C_SD)
/JTCLK: J7.6, R126.2, U2.F16 (JTCLK)
/JTDI: J7.8, R163.2, U2.G16 (JTDI)
/JTDO: J7.9, R162.2, U2.G17 (JTDO)
/JTMS: J7.7, R127.2, U2.G18 (JTMS)
/JTRST_N: J7.10, R90.2, U2.F17 (JTRST_N)
/KEY: R116.2, U15.26 (KEY)
/MDC: R135.2, R136.2, U2.T15 (MDC)
/P0_LED_0: R149.2, R150.2, U2.AA17 (ESW_P0_LED_0)
/P0_LED_1: R155.2, R156.2, U2.W16 (ESW_P0_LED_1)
/P1_LED_0: R151.2, R152.2, U2.Y16 (ESW_P1_LED_0)
/PB_INT: R121.1, U2.V18 (GE2_TXCLK), U15.13 (L3)
/PCIE_CK0_N: J10.53 (REFCLKn), R105.1, R110.1
/PCIE_CK0_P: J10.55 (REFCLKp), R104.1, R109.1
/PCIE_CK1_N: J5.11 (REFCLK-), R107.1, R112.1
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

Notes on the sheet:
# eth diff 100Ω: - [W/L2] Width=0.1mm; Trace spacing=0.15; Trace copper=0.15
# USB3 diff 90Ω: - [W/L2] Width=0.14mm; Trace spacing=0.15; Trace copper=0.25 - [L2/W/L4] Width=0.12mm; Trace spacing=0.15; Trace copper=0.25 - [L4/W/L6] Width=0.12mm; Trace spacing=0.15; Trace copper=0.25 Для дифференциальных пар дуплексной линии USB 3.0 поддержка перекрёстного соединения сигнальн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
# DDR | 1 | ADDR,CMD | RA[14:0]| DDR_~{RAS}, DDR_~{CAS}, ~{WE}| ~{CS},ODT,CKE | | 2 | CLK | DDR_CLK_N/P | | 3 | DATA LANE0 | DDR_QM0, DDR_QS0_N/P, DDR_Q0[7:0] | | 4 | DATA LANE1 | DDR_QM1, DDR_QS1_N/P, DDR_Q1[8:14] | diff 90-95Ω: - [W/L2] Width=0.15mm; Trace Spacing=0.21 - [L2/W/L4] Width=0.14mm; T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
# pcie diff 85Ω: - [W/L2] Width=0.14mm; Trace spacing=0.127; Trace copper=0.127
Power bank
DDR3
Secondary power
Primary power
!!!
SYS
UART no STD!
SPI_CS1_N
Interface unit
M.2 connector
I2C/UART no STD!
Ethernet
SPI_CS0_N
SPI_CLK
USB3
OLED
SPI Flash
mPCIe connector

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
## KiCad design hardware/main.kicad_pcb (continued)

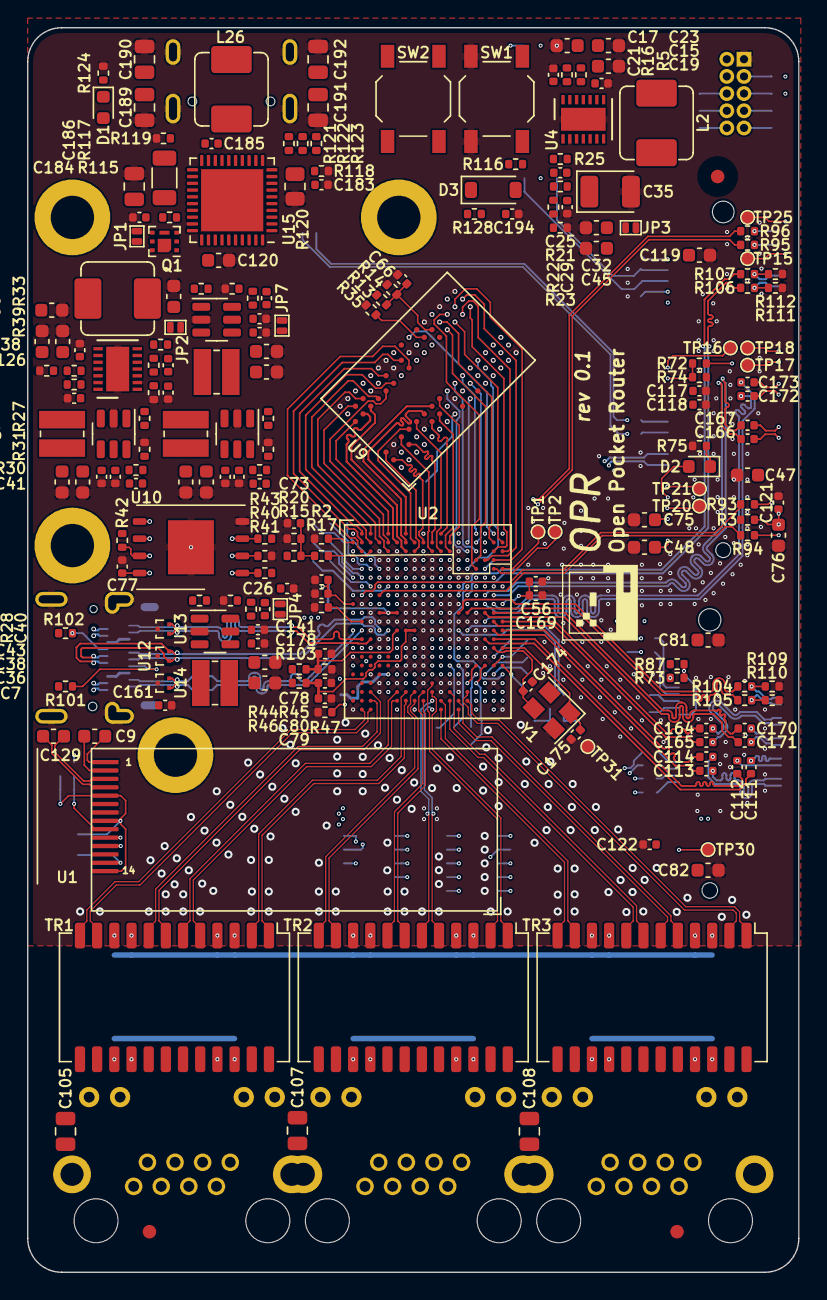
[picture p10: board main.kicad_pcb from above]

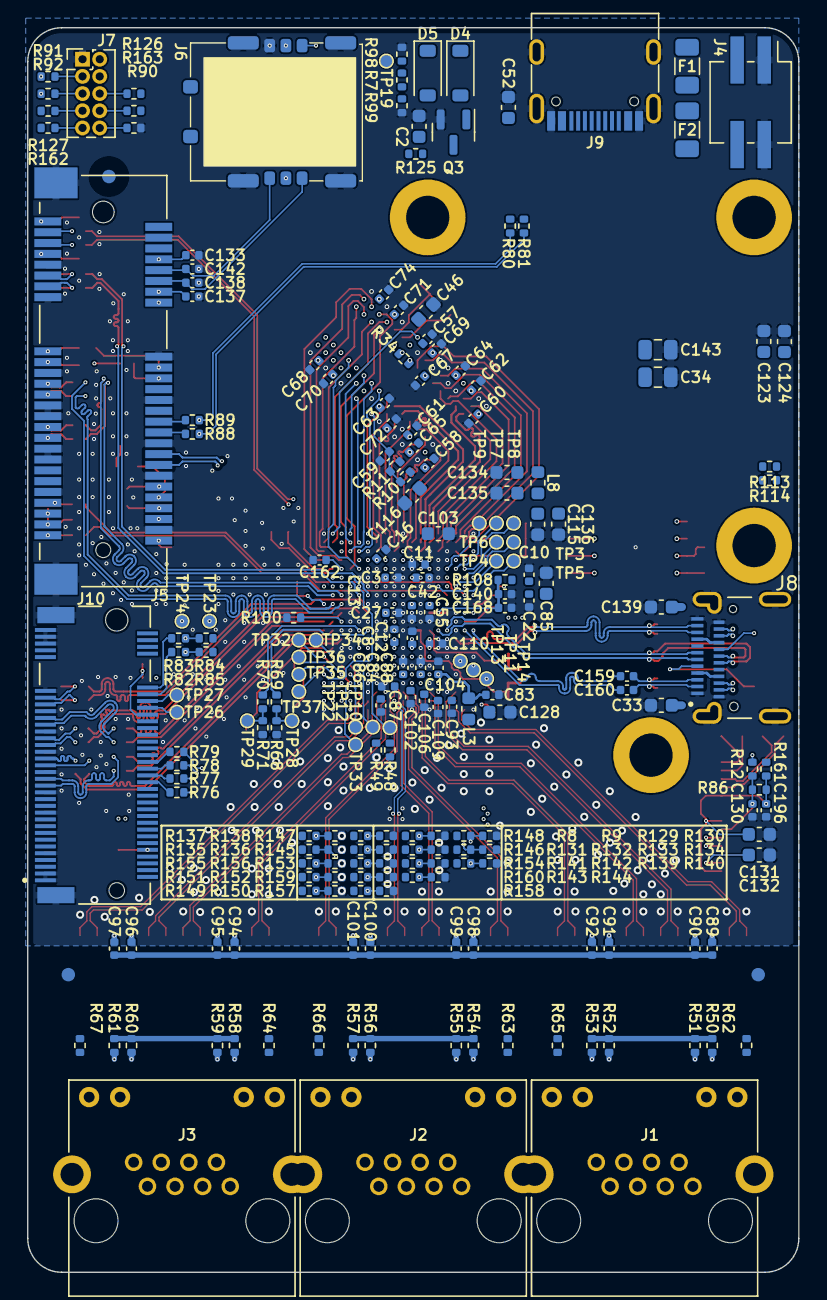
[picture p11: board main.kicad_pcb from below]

Board: 6 copper layers, 57.0 x 92.0 mm, 432 parts (217 on the bottom side), 366 nets.

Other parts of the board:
J6: 1042240820
R74: 4.7k; R_0402_1005Metric

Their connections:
+3V3: R74.2; also elsewhere on the board

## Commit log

2022-12-12 ad dcdc
    [main.kicad_pcb, main.kicad_sch]
2022-12-13 update dcdc
    [main.kicad_sch]
2022-12-14 add eth and usb
    [main.kicad_sch]
2022-12-15 add ram and rom
    [main.kicad_sch]
2022-12-16 add pin layout ram and usb
    [main.kicad_sch]
2022-12-18 add cpu and pin layout
    [main.kicad_sch]
2022-12-22 add mt7603
    [main.kicad_sch]
2022-12-23 add rf
    [main.kicad_sch]
2022-12-24 add oled
    [main.kicad_sch]
2022-12-24 init pcb
    [charger.kicad_sch, ethernet.kicad_sch, interface.kicad_sch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]
2022-12-24 update pcb
    [interface.kicad_sch, main.kicad_pcb, main.kicad_sch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]
2022-12-26 trace ram
    [main.kicad_pcb]
2023-05-05 fix pcb
    [main.kicad_pcb]
2023-09-07 update cap and dru
    [charger.kicad_sch, ethernet.kicad_sch, interface.kicad_sch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]
2023-09-07 add mini-pcie and m2
    [main.kicad_pcb, main.kicad_sch, memory.kicad_sch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]
2023-09-08 add mPCI-e and m2 conn
    [main.kicad_pcb, main.kicad_sch]
2023-09-08 pinlayout for pci-e
    [interface.kicad_sch, main.kicad_pcb, main.kicad_sch]
2023-09-09 circuits are combined
    [charger.kicad_sch, charger_IP5318.kicad_sch, ethernet.kicad_sch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]
2023-09-10 update 100923
    [main.kicad_pcb, main.kicad_sch]
2023-09-10 update sch
    [main.kicad_pcb, main.kicad_sch]
2023-09-10 update outline
    [main.kicad_pcb]
2023-09-12 updated rules for differential pairs
    [main.kicad_pcb, main.kicad_sch]
2023-09-12 calc Impedance and mark wire
    [main.kicad_pcb, main.kicad_sch]
2023-09-13 update pin layout
    [main.kicad_pcb, main.kicad_sch]
2023-09-13 update silk
    [main.kicad_pcb]
2023-09-13 fix silk
    [main.kicad_pcb]
2023-09-15 custom layout ddr3
    [main.kicad_pcb, main.kicad_sch]
2023-09-16 fixed gap on ddr lines
    [main.kicad_pcb]
2023-09-16 fixed ddr tracing, usb tracing
    [main.kicad_pcb, main.kicad_sch]
2023-09-16 track tracing
    [main.kicad_pcb, main.kicad_sch]
2023-09-17 eth tracing
    [main.kicad_pcb]
2023-09-18 update vias
    [main.kicad_pcb]
2023-09-18 impedance matching
    [main.kicad_sch]
2023-09-20 trace completed
2023-09-20 fix mask via for bga
    [main.kicad_sch]
2023-09-22 fix `Hole to hole clearance(Different nets)`
2023-09-23 fix `Via to Track`
2023-09-23 add usb hub and wifi
    [main.kicad_sch]
2023-10-01 fix U.FL_Hirose
    [main.kicad_sch]
2023-10-04 fix drc; add fasteners
    [main.kicad_sch]
2023-10-22 fix prj; description -> Comments
    [main.kicad_sch]
2023-10-28 close #5
    [main.kicad_sch]
2023-10-28 close #3
    [main.kicad_sch]
2024-04-22 add case
